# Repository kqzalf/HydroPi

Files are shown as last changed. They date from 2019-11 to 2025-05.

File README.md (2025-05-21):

# HydroPi

## Overview
HydroPi is a project that uses a Raspberry Pi and Arduino to monitor environmental conditions using various sensors. The system logs sensor data and provides a web interface for viewing the data.

## Hardware List
- Arduino Uno R3
- Raspberry Pi 5
- Samsung 32GB EVO Plus Class 10 Micro SDHC
- diymore ph-4502c (pH sensor)
- tds meter v1.0
- Adafruit CCS811 Air Quality Sensor
- Gowoops DHT22 Temp/Humidity Sensor
- Adafruit TSL2591 Digital Light Sensor
- Autofocus for Raspberry Pi Camera
- DS18B20 Waterproof Temperature Sensor Probe Module
- Capacitive Soil Moisture Sensor

## Wiring Instructions
- **DHT22 (AM2302)**: 
  - + to 3V3 (Pin 1)
  - OUT to BCM 17 (Pin 11)
  - - to Ground (Pin 6)
- **TSL2591**:
  - VIN to 5V Power (Pin 2)
  - GND to Ground (Pin 6)
  - SDA to SDA (Pin 3)
  - SCL to SCL (Pin 5)
- **CCS811**:
  - VIN to 5V Power (Pin 4)
  - GND to Ground (Pin 14)
  - SDA to SDA (Pin 3)
  - SCL to SCL (Pin 5)
  - WAKE to Ground (Pin 20)

## Directory Structure
- `rev1/`
  - `arduino/`
    - `sensors/`
      - `pH_sensor/`
      - `tds_sensor/`
      - `water_temp_sensor/`
      - `analogue_soil_moisture_sensor/`
    - `HydropiSensorModule/`
  - `Pi/`
    - `Web/`
      - `mainSensors.php`
      - `auxSensors.php`
      - `functions.php`
      - `logSubmit.php`
      - `getPic.php`
      - `handle.php`
      - `index.php`
    - `Python/`
      - `sensors.py`
      - `Sense_v1.1.py`
      - `dashboard/`
        - `app.py`
        - `templates/`
          - `dashboard.html`
        - `requirements.txt`

## Setup Instructions
1. **Raspberry Pi Setup**:
   - Install required Python packages:
     ```bash
     sudo pip3 install Adafruit_DHT
     sudo apt-get install python-picamera python3-picamera python-rpi.gpio
     sudo pip3 install --upgrade picamera[array]
     sudo apt-get install python-opencv
     ```
   - Ensure the Arduino is connected to the Raspberry Pi via USB.

2. **Arduino Setup**:
   - Upload the appropriate Arduino sketches for each sensor.

## Usage Instructions
- Run the main sensing script:
  ```bash
  python3 Sense_v1.1.py
  ```
- The script will log sensor data to `/var/www/html/logs/mainlog.log`.

## Local Dashboard
A local dashboard is available to view the latest and historical sensor data. It runs on your Pi and is accessible at http://localhost:5000 or your Pi's IP address.

### Setup
1. Install Flask:
   ```bash
   pip3 install -r rev1/Pi/Python/dashboard/requirements.txt
   ```
2. Run the dashboard:
   ```bash
   python3 rev1/Pi/Python/dashboard/app.py
   ```

### Features
- Shows the latest sensor readings
- Displays a chart of the last 24 hours (up to 144 readings)
- Auto-refreshes every 10 seconds if new data is available
- Manual refresh button

## License
This project is licensed under the terms of the LICENSE file included in the repository.

## CI/CD
This project uses GitHub Actions for continuous integration. The workflow runs on every push and pull request to the `main` branch. It installs dependencies and runs tests using pytest.

## Linting
To ensure code quality, pylint is used for linting Python code. A `.pylintrc` file is included in the `rev1/Pi/Python/` directory to configure linting rules. Run the following command to lint the Python files:
```bash
pylint rev1/Pi/Python/*.py
```

## Testing
Tests are written using pytest and are located in `rev1/Pi/Python/test_sensors.py`. To run the tests, execute:
```bash
pytest rev1/Pi/Python/
```

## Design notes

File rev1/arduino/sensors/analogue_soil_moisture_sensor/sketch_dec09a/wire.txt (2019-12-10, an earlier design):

gnd > gnd
vcc > 5v
aout > analogue pin 0

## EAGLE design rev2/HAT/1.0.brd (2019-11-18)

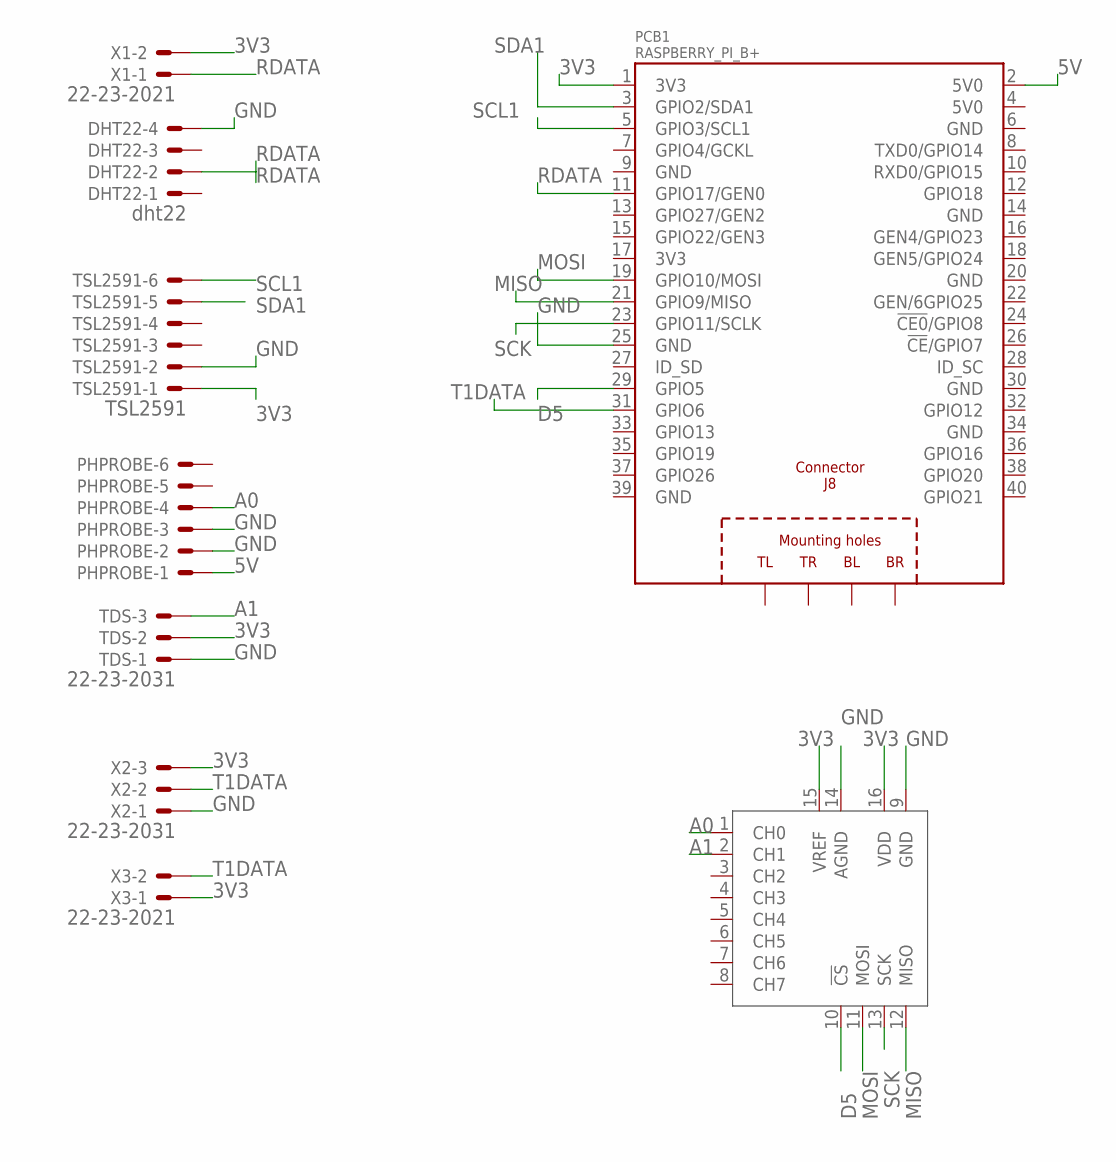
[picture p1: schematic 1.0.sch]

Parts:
DHT22: dht22; 22-23-2041
PCB1: RASPBERRY_PI_B+
PHPROBE: 22-23-2061
TDS: 22-23-2031
TSL2591: TSL2591; 22-23-2061
U$1: MCP3008P; DIL16
X1, X3: 22-23-2021
X2: 22-23-2031

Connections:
3V3: PCB1.1 (3V3), TDS.2, TSL2591.1, U$1.15 (VREF), U$1.16 (VDD), X1.2, X2.3, X3.1
5V: PCB1.2 (5V0), PHPROBE.1
A0: PHPROBE.4, U$1.1 (CH0)
A1: TDS.3, U$1.2 (CH1)
D5: PCB1.29 (GPIO5), U$1.10 (!CS)
GND: DHT22.4, PCB1.25 (GND), PHPROBE.2, PHPROBE.3, TDS.1, TSL2591.2, U$1.9 (GND), U$1.14 (AGND), X2.1
MISO: PCB1.21 (GPIO9/MISO), U$1.12 (MISO)
MOSI: PCB1.19 (GPIO10/MOSI), U$1.11 (MOSI)
RDATA: DHT22.2, PCB1.11 (GPIO17/GEN0), X1.1
SCK: PCB1.23 (GPIO11/SCLK), U$1.13 (SCK)
SCL1: PCB1.5 (GPIO3/SCL1), TSL2591.6
SDA1: PCB1.3 (GPIO2/SDA1), TSL2591.5
T1DATA: PCB1.31 (GPIO6), X2.2, X3.2

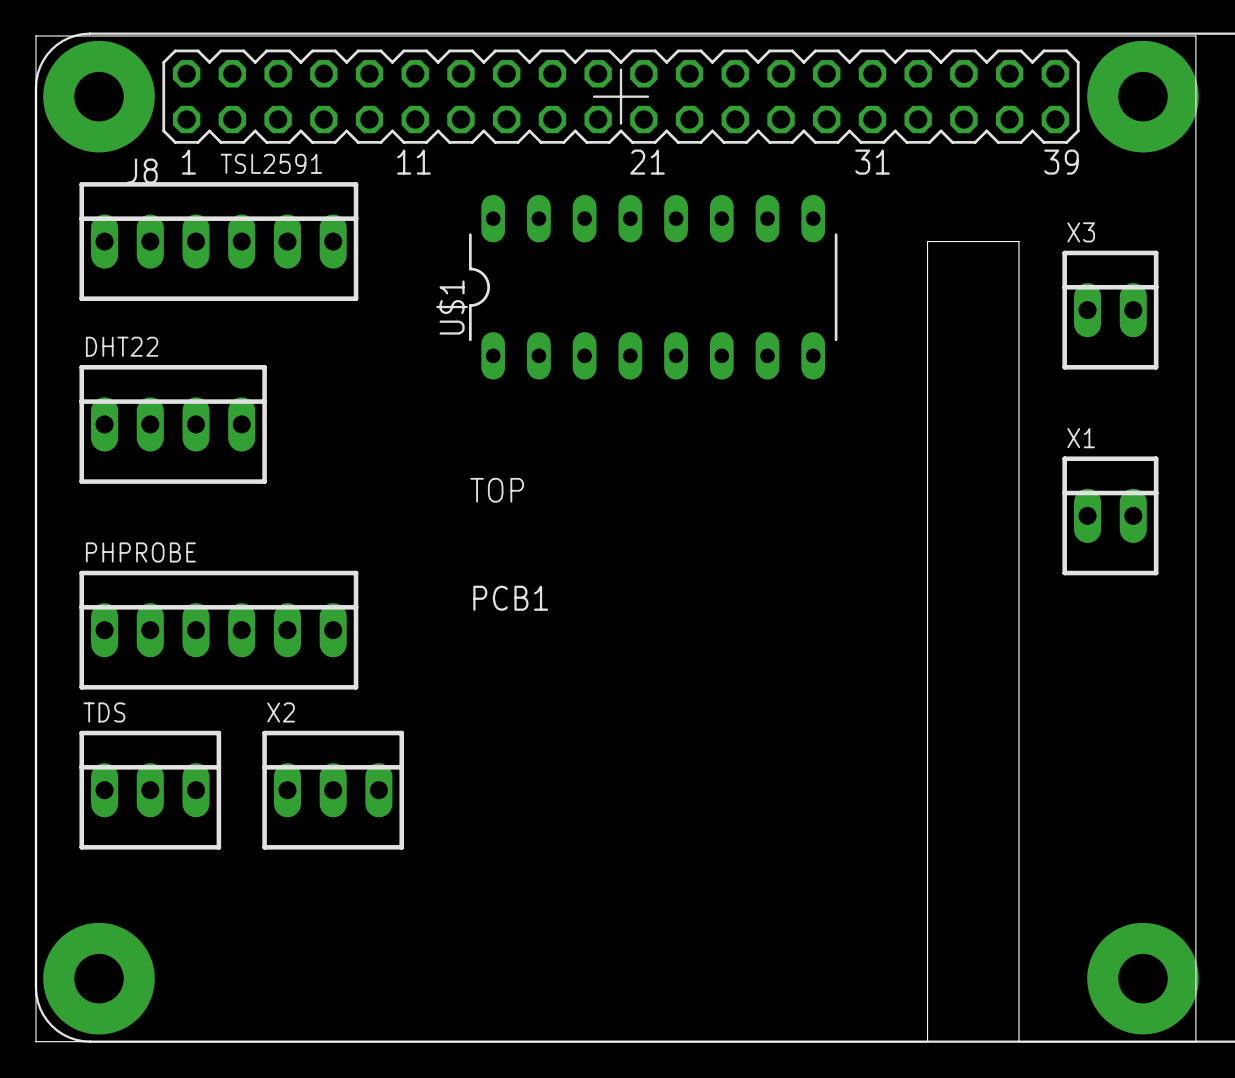
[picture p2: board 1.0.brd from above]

Board: 2 copper layers, 64.4 x 55.9 mm, 9 parts (0 on the bottom side), 13 nets.

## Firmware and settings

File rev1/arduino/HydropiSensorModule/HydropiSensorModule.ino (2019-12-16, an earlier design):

#include "Functions.h"

void setup() {
  // put your setup code here, to run once:
Serial.begin(9600);
}

void loop() {
  // put your main code here, to run repeatedly:
  int val1 = PhSensor(20.48, A2, 32);
  int val2 = TdsSensor(A1,32);
  int val3 = SoilMSensor(A0);
  int val4 = WaterTempSensor(2);
  Serial.print(val1);
  Serial.print("*");
  Serial.print(val2); // debug value
  Serial.print("*");
  Serial.print(val3);
  Serial.print("*");
  Serial.print(val4);
  Serial.print("\n");
delay(1000); 
//577 to 581 dry 
//291 - 293 submerged in water
}

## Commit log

2019-11-18 uploading boards
    [1.0.brd, 1.0.sch]
2019-11-18 Add files via upload
    pH sensor Scripts
2019-11-23 file orgonization
    cleaned up file structure. we are working on rev1 now
    [1.0.brd, 1.0.sch]
2019-11-24 tds sensor done
    can plug water temp into this for more accuracy but its give or take 5ppm off
2019-11-26 Add files via upload
    it doesint read correctly every other read. change timer maybe, should not be an issue, just be aware of it.
2019-12-04 added sense.py
    sense.py grabs the data from sensors,and writes it to a logfile that the web interface can read and use.
2019-12-07 Add files via upload
    This is the currently working script for our dht22 sensor. 12/7/19
2019-12-09 Add files via upload
    executes sensor functions, and writes to a file. dependent on Functions.py (Must be in same folder)
2019-12-09 Add files via upload
    contains functions that run sensors, Sense_v1.0.py is dependent on this. (keep in same folder).
